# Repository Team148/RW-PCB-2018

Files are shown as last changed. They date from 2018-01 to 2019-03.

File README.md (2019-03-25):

# RW-PCB-2018

These PCBs are Robowrangler versions of the Talon SRX Breakout Board and a simple CAN Bus Daisy Chain Board. This is standardized around the Molex SL latching type of connector (50-57-9405 + 16-02-0087). This type of connector also connects to US Digital S5 Encoders with the same pinout pattern.

```
Talon SRX Breakout Board BOM
  Harwin M50-3000745     Qty 1 (Cut off outer 4 pins)
  Molex 15-91-3053       Qty 1
  Lite-On LTST-C150KGKT  Qty 1 (Optional)
  Susumu RG3216P-2201-D-T5   Qty 1 (Optional)
  
Based on MVRT / FRC Team 115's Open Source Design.
```

CAN Devices need to be wired into a Molex SL type connectors(50-579404 + 16-02-0087) with the H (green) paired in the middle 2 positions,
and the L's on the outer two positions. The twisted pairs need to be next to each other. Devices must be plugged
in Sequentially and the last device must be terminated with an 120 Ohm resistor (can be PDP). These boards can also
be daisy chained if above 18 devices, simply attach port 15 to another board's port 0.The port numbers are just for reference,
they do not have to correspond to CAN ID.
```
RW CAN
  Molex 70555-0038       Qty 18
```

GERBER Files are exported for SEEEDSTUDIO's FUSION Service

Optional: We recommend using the Belden 8723 060100 wire for encoders and for extending a CAN bus to/from since it both twisted pairs are individually shielded.

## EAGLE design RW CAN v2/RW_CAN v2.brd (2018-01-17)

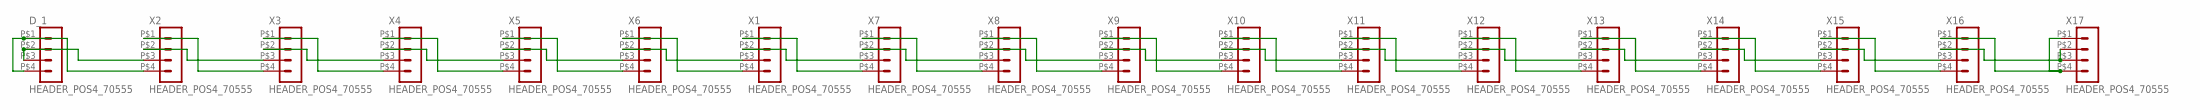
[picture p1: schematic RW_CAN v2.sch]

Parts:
D_1: HEADER_POS4_70555; 70555-POS4
X1, X2, X3, X4, X5, X6, X7, X8, X9, X10, X11, X12, X13, X14, X15, X16, X17: HEADER_POS4_70555; 70555-POS4

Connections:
unnamed: D_1.P$1 (1), D_1.P$4 (4), X2.P$4 (4)
unnamed: D_1.P$2 (2), D_1.P$3 (3), X2.P$3 (3)
unnamed: X3.P$2 (2), X4.P$3 (3)
unnamed: X2.P$2 (2), X3.P$3 (3)
unnamed: X2.P$1 (1), X3.P$4 (4)
unnamed: X3.P$1 (1), X4.P$4 (4)
unnamed: X4.P$2 (2), X5.P$3 (3)
unnamed: X4.P$1 (1), X5.P$4 (4)
unnamed: X5.P$2 (2), X6.P$3 (3)
unnamed: X5.P$1 (1), X6.P$4 (4)
unnamed: X1.P$3 (3), X6.P$2 (2)
unnamed: X1.P$4 (4), X6.P$1 (1)
unnamed: X1.P$2 (2), X7.P$3 (3)
unnamed: X1.P$1 (1), X7.P$4 (4)
unnamed: X7.P$2 (2), X8.P$3 (3)
unnamed: X7.P$1 (1), X8.P$4 (4)
unnamed: X8.P$2 (2), X9.P$3 (3)
unnamed: X8.P$1 (1), X9.P$4 (4)
unnamed: X9.P$2 (2), X10.P$3 (3)
unnamed: X9.P$1 (1), X10.P$4 (4)
unnamed: X10.P$2 (2), X11.P$3 (3)
unnamed: X10.P$1 (1), X11.P$4 (4)
unnamed: X11.P$2 (2), X12.P$3 (3)
unnamed: X11.P$1 (1), X12.P$4 (4)
unnamed: X12.P$2 (2), X13.P$3 (3)
unnamed: X12.P$1 (1), X13.P$4 (4)
unnamed: X13.P$1 (1), X14.P$4 (4)
unnamed: X13.P$2 (2), X14.P$3 (3)
unnamed: X14.P$2 (2), X15.P$3 (3)
unnamed: X14.P$1 (1), X15.P$4 (4)
unnamed: X15.P$2 (2), X16.P$3 (3)
unnamed: X15.P$1 (1), X16.P$4 (4)
unnamed: X16.P$2 (2), X17.P$2 (2), X17.P$3 (3)
unnamed: X16.P$1 (1), X17.P$1 (1), X17.P$4 (4)

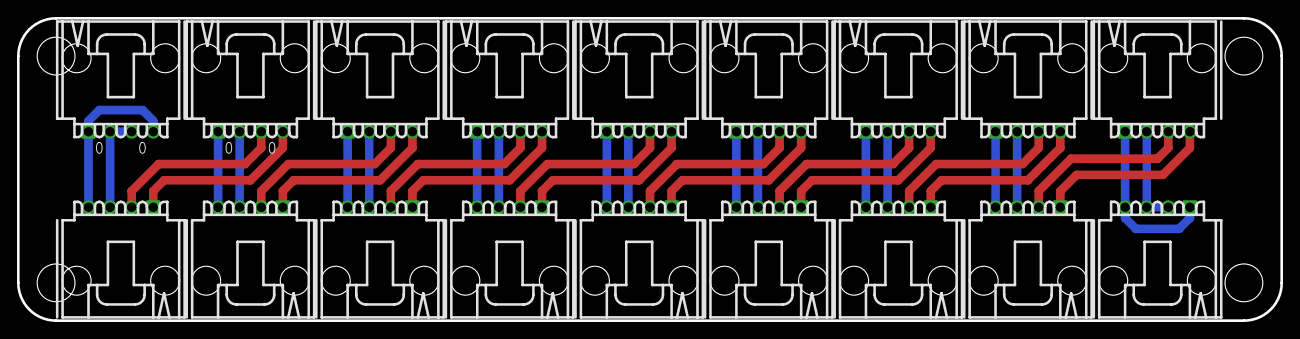
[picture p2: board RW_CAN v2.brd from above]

Board: 2 copper layers, 148.6 x 35.6 mm, 18 parts (0 on the bottom side), 34 nets.

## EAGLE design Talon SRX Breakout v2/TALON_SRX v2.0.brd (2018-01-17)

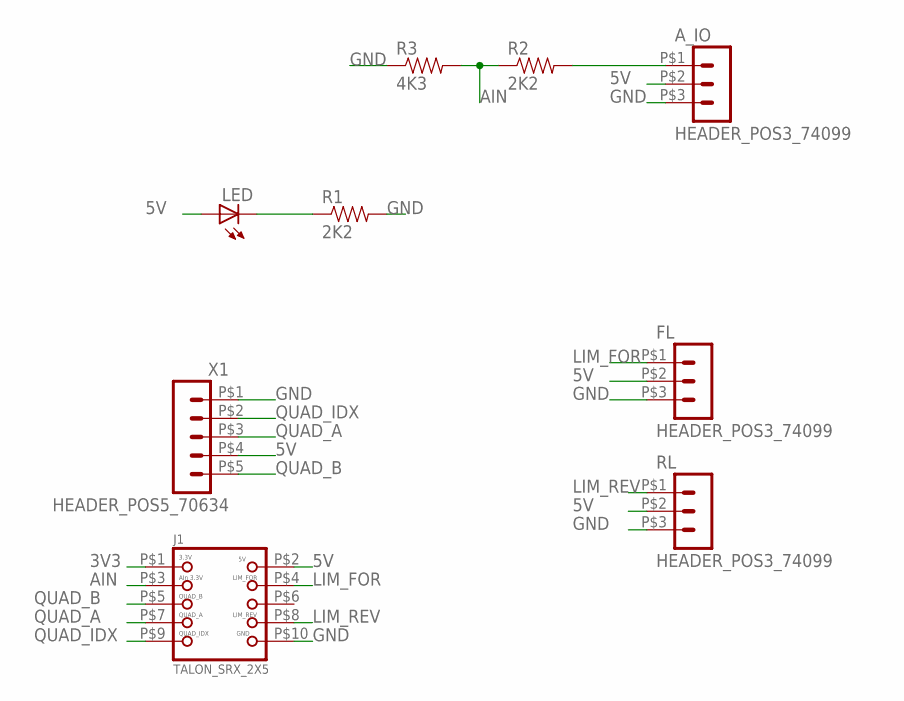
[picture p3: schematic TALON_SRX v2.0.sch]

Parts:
A_IO: HEADER_POS3_74099; 74099-POS3
FL: HEADER_POS3_74099; 74099-POS3
J1: TALON_SRX_2X5; 2X5-0.05-HEADER
LED: LEDSMT1206; 1206
R1, R2: 2K2; 1206
R3: 4K3; 1206
RL: HEADER_POS3_74099; 74099-POS3
X1: HEADER_POS5_70634; 70634-POS5

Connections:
3V3: J1.P$1 (1)
5V: A_IO.P$2 (2), FL.P$2 (2), J1.P$2 (2), LED.A, RL.P$2 (2), X1.P$4 (4)
AIN: J1.P$3 (3), R2.1, R3.2
GND: A_IO.P$3 (3), FL.P$3 (3), J1.P$10 (10), R1.2, R3.1, RL.P$3 (3), X1.P$1 (1)
LIM_FOR: FL.P$1 (1), J1.P$4 (4)
LIM_REV: J1.P$8 (8), RL.P$1 (1)
unnamed: A_IO.P$1 (1), R2.2
unnamed: LED.C, R1.1
QUAD_A: J1.P$7 (7), X1.P$3 (3)
QUAD_B: J1.P$5 (5), X1.P$5 (5)
QUAD_IDX: J1.P$9 (9), X1.P$2 (2)

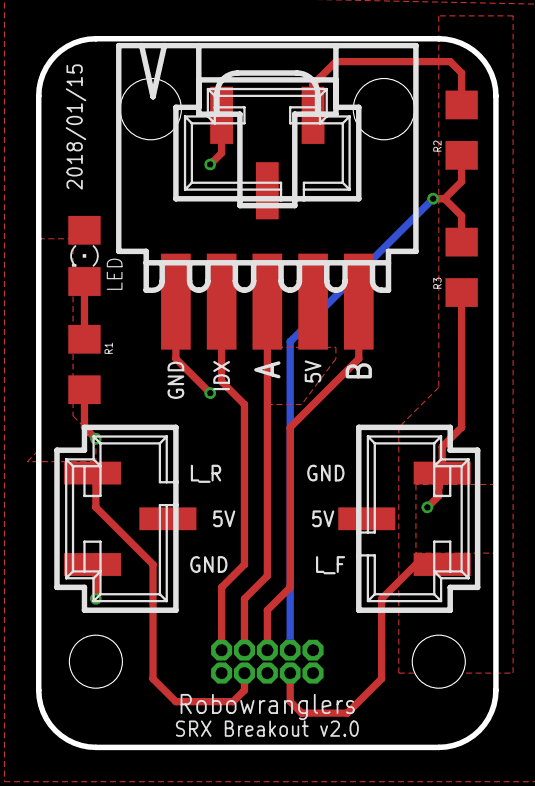
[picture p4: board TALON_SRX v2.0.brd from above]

Board: 2 copper layers, 25.4 x 39.4 mm, 9 parts (1 on the bottom side), 10 nets.

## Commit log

2018-01-15 WIP
    Added Analog Input and Changed SMD size to 1206
    [TALON_SRX v2.0.brd, TALON_SRX v2.0.sch]
2018-01-17 Made Changes
    [RW_CAN v2.brd, RW_CAN v2.sch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]
2018-01-18 Submitted to SeeedFusion
    Production Version
    [RW_CAN v2.GBL, RW_CAN v2.GBO, RW_CAN v2.GBP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]

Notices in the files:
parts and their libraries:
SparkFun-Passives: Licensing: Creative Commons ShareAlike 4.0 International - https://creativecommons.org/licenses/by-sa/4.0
